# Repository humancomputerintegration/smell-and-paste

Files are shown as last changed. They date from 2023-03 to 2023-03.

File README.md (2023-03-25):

# Smell & Paste toolkit

This is a repository for the Smell & Paste low-fidelity prototyping toolkit for olfactory experiences, which was presented at ACM CHI 2023. The kit is a cassette that takes in scratch-and-sniff stickers by [Jas Brooks](https://jasbrooks.net) and [Pedro Lopes](https://plopes.org) at the University of Chicago's [Human Computer Integration Lab](https://lab.plopes.org/).

[Paper](https://lab.plopes.org/published/2023-CHI-SmellPaste.pdf) | [CHI Talk Video](https://youtu.be/vVBhl13b0PE)

**Original Paper Abstract:** Low-fidelity prototyping is so foundational to Human-Computer Interaction, appearing in most early design phases. So, how do experts prototype olfactory experiences? We interviewed eight experts and found that _they do not_ because _no process supports this_. Thus, we engineered Smell & Paste, a low-fidelity prototyping toolkit. Designers assemble olfactory proofs-of-concept by pasting scratch-and-sniff stickers onto a paper tape. Then, they test the interaction by advancing the tape in our 3D-printed (or cardboard) cassette, which releases the smells via scratching. Our toolkit uses commodity materials; keeps iterations quick, approachable, and cheap; and circumvents electronics, programming, and chemical handling. We evaluated Smell & Paste in two studies. We found that the toolkit was approachable to people of any technical background and that novices and experts appropriated and extended the toolkit, making it personalized. Novices produced prototypes quickly, and experts were excited about the kit's technical affordances and integrating it into their practice.

## Putting together a kit

So you want to try out Smell & Paste!

### 3D Printed version

`3D_Print` contains all the files for the 3D printed version of the cassette. It contains both the parametric Fusion 360 file (`Cassette_3dPrinted_v69.f3d`) as well as all the STL files for printing off the bat (`\STL`). You will have to print two of the rollers (`SaP_Nylon_Roller.stl`) and spools (`SaP_Nylon_Spool.stl`) for one cassette.

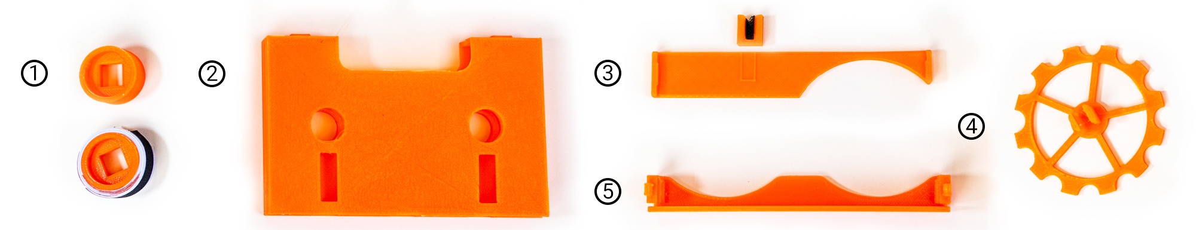
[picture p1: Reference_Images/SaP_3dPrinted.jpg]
Photographs of the 3D printed kit laid out.


| Item | Sourcing | Quantity | Example Source | Unit Cost  | Total Cost | Note |
|---|---|---|---|---|---|---|
| [Case (Bottom)](https://github.com/humancomputerintegration/smell-and-paste/blob/main/3D_Print/STL/SaP_Nylon_CaseBottom.stl) | 3D Print | 1 | | ~ | ~ | |
| [Case (Top)](https://github.com/humancomputerintegration/smell-and-paste/blob/main/3D_Print/STL/SaP_Nylon_CaseTop.stl) | 3D Print | 1 | | ~ | ~ | |
| [Scratch plate](https://github.com/humancomputerintegration/smell-and-paste/blob/main/3D_Print/STL/SaP_Nylon_ScratchPlate.stl) | 3D Print | 1 | | ~ | ~ | |
| [Comb](https://github.com/humancomputerintegration/smell-and-paste/blob/main/3D_Print/STL/SaP_Nylon_Comb.stl) | 3D Print | 1 | | ~ | ~ | |
| [Driver](https://github.com/humancomputerintegration/smell-and-paste/blob/main/3D_Print/STL/SaP_Nylon_Driver.stl) | 3D Print | 1 | | ~ | ~ | |
| [Idle rollers](https://github.com/humancomputerintegration/smell-and-paste/blob/main/3D_Print/STL/SaP_Nylon_Roller.stl) | 3D Print | 2 | | ~ | ~ | |
| [Spools](https://github.com/humancomputerintegration/smell-and-paste/blob/main/3D_Print/STL/SaP_Nylon_Spool.stl) | 3D Print | 2 | | ~ | ~ | |
| Ream of Printer/Copy Paper (20lb) | At home or Purchase | 1 | | $10.00 | $10.00 | Any kind of paper at home works! |
| Tape (Splicing) | At home or Purchase | 1 | [Bari Zaki Studio](https://www.barizaki.com/shop/washi-tape-bookshelf) | $6.00 | $6.00 | Preferably a flexible tape like painter's tape. We recommend Washi tape for how thin and flexible it is! |
| Tape (Spool) | At home or Purchase | 1 | [Home Depot](https://www.homedepot.com/p/Nashua-Tape-1-89-in-x-55-yd-394-General-Purpose-Duct-Tape-in-Silver-Sealer-1529728/100080300) | $4.88 | $4.88 | Preferably a stickier tape to bind the paper tape to the spools. We recommend cheap duct tape. |
| Super glue | At home or Purchase | 1 | [Home Depot](https://www.homedepot.com/p/Loctite-0-14-fl-oz-Ultra-Gel-Control-Super-Glue-1363589/202020461) | $5.68 | $5.68 | To glue the hinges for the 3D printed cassette. Alternatively, you can use duct tape as a hinge. |
| Velcro (hook-and-loop fasteners) with Sticky Backing	| At home or Purchase | 1  | [Home Depot](https://www.homedepot.com/p/VELCRO-Brand-3-1-2-in-x-3-4-in-Sticky-Back-Strips-4-Pack-90075/202261913) | $3.28 | $3.28 | For the comb. |
| Scratch-and-sniff stickers! | At home or Purchase | ~ | Check out Dataset | ~ | ~ | |
| | | | | **Total Cost** | $29.84 | To get things started! |

Please consider sourcing materials from local stores instead of Amazon, if you can! A lot of these items can be found in your home, hardware stores, general stores, and stationary stores.

All 3D printed parts do not need any support structures except for the spools (and - even then - could probably do fine without).

### Cardboard version

`Cardboard` contains all the files for the cardboard version of the cassette. It contains one version for lasercutters (`\Lasercut`) and one for manual cutting using an Xacto knife (`\Manual`). Please note that if you are lasercutting the cardboard version, you will have to leave the pieces to ventilate so that there is no residual burn odor (you can also adjust the settings to decrease burning as much as possible, and can also put the pieces with an ozone generator to speed up the deodorization). For manual cutting, print out the pages (PDF) and paste them on 2.5 mm cardboard. Then use an exacto knife to follow lines.

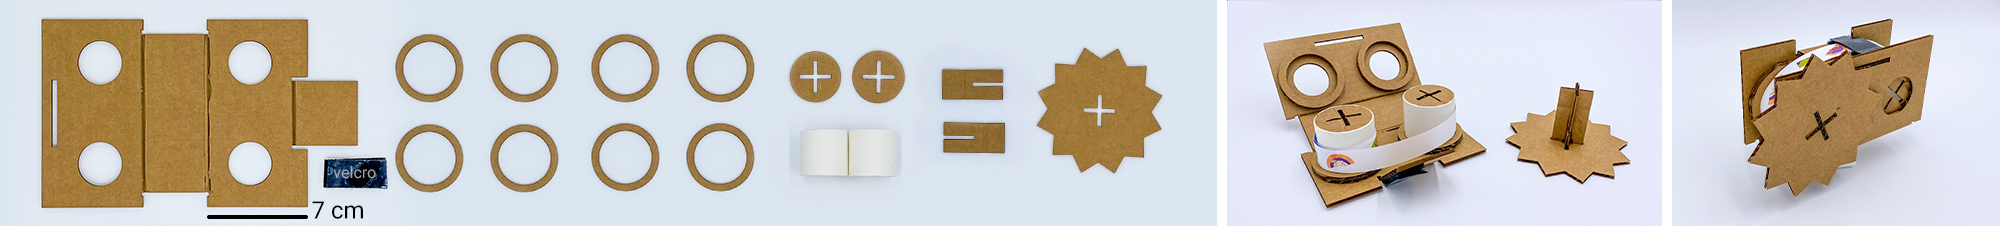
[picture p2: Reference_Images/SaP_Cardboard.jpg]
Photographs of the cardboard kit laid out and assembled.


| Item | Sourcing | Quantity | Example Source | Unit Cost  | Total Cost | Note |
|---|---|---|---|---|---|---|
| Cardboard (2.75mm) | 3D Print | 2 | | ~ | ~ | Amazon packages are typically the perfect thickness for this. |
| 1.6in Diameter Paper Tube (Spools) | 3D Print | 2 | | ~ | ~ | Cut the tube to have 2 tubes of length 4cm. |
| Ream of Printer/Copy Paper (20lb) | At home or Purchase | 1 | | $10.00 | $10.00 | Any kind of paper at home works! |
| Tape (Splicing) | At home or Purchase | 1 | [Bari Zaki Studio](https://www.barizaki.com/shop/washi-tape-bookshelf) | $6.00 | $6.00 | Preferably a flexible tape like painter's tape. We recommend Washi tape for how thin and flexible it is! |
| Tape (Spool) | At home or Purchase | 1 | [Home Depot](https://www.homedepot.com/p/Nashua-Tape-1-89-in-x-55-yd-394-General-Purpose-Duct-Tape-in-Silver-Sealer-1529728/100080300) | $4.88 | $4.88 | Preferably a stickier tape to bind the paper tape to the spools. We recommend cheap duct tape. |
| Glue stick | At home or Purchase | 1 | [Walgreens](https://www.walgreens.com/store/c/elmer's-disappearing-purple-school-glue-sticks/ID=prod17798-product) | $3.79 | $3.79 | To glue cardboard pieces together. together. |
| Velcro (hook-and-loop fasteners) with Sticky Backing | At home or Purchase | 1 | [Home Depot](https://www.homedepot.com/p/VELCRO-Brand-3-1-2-in-x-3-4-in-Sticky-Back-Strips-4-Pack-90075/202261913) | $3.28 | $3.28 | For comb. |
| Scratch-and-sniff stickers! | At home or Purchase | ~ | | ~ | ~ | |
| | | | | Total Cost | $26.56 | To get things started! |

Please consider sourcing materials from local stores instead of Amazon, if you can! A lot of these items can be found in your home, hardware stores, general stores, and stationary stores.

### Sourcing scratch-and-sniff stickers

For our toolkit to be practical, you'll need scratch-and-sniff stickers. Commercial scratch-and-sniff stickers for children are incredibly accessible and cheap, including good and bad scents. We created a dataset of 800 scratch-and-sniff stickers from 22 brands to facilitate sticker selection. We manually extracted each sticker’s scent, dimensions, and price per cm2. The dataset includes (nominally) 538 unique scents, depicting a wide variety at costs as low as 0.00035 USD per cm2. [You can find its CSV here!](https://github.com/humancomputerintegration/smell-and-paste/blob/main/CommercialSaS_v00.csv) (Jas recommends Just For Laughs' [Stink Factory stickers](https://www.thestinkfactory.com/) for their odor variety and reasonable prices.)

## Licensing & Citing

The cassette and documentation is released under the CC BY 4.0 License (just needs attribution to Jas Brooks and Pedro Lopes). We encourage people to remix this to their heart's content!

When using or building upon this device or dataset **in an academic publication**, please consider citing our paper:

Jas Brooks and Pedro Lopes. 2023. “Smell & Paste: Low-Fidelity Prototyping for Olfactory Experiences.” In Proceedings of the 2023 CHI Conference on Human Factors in Computing Systems (CHI ’23). Association for Computing Machinery, New York, NY, USA. DOI:10.1145/3544548.3580680

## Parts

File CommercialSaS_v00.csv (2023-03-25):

Vendor Country | Distributor | Brand | Scent | URL | Production Status | Cost ($) | Unit | Count | Price per Unit ($) | Usable Area Dimensions (cm) | Usable Unit Surface Area (cm2) | Price per cm2 ($/cm2) | Assortment | Purchased | Accessed | Notes
US | Horiey | Horiechaly | Bubblegum | https://www.amazon.com/HORIECHALY-Stickers-Different-Teachers-Stickers/dp/B088D5HZJ5/ |  | $ 14.97 | Sheet | 80 | $ 0.19 | 31.75 x 17.022 | 540.32 | 0.00035 | Mixed |  | 2020/11/06
US | Horiey | Horiechaly | Rose | https://www.amazon.com/HORIECHALY-Stickers-Different-Teachers-Stickers/dp/B088D5HZJ5/ |  | $ 14.97 | Sheet | 80 | $ 0.19 | 31.75 x 17.038 | 540.32 | 0.00035 | Mixed |  | 2020/11/06
US | Horiey | Horiechaly | Apple | https://www.amazon.com/HORIECHALY-Stickers-Different-Teachers-Stickers/dp/B07Z4C5DNJ |  | $ 15.97 | Sheet | 68 | $ 0.23 | 31.75 x 17.018 | 540.32 | 0.00043 | Mixed |  | 2020/11/06
US | Horiey | Horiechaly | Avocado | https://www.amazon.com/HORIECHALY-Stickers-Different-Teachers-Stickers/dp/B07Z4C5DNJ |  | $ 15.97 | Sheet | 68 | $ 0.23 | 31.75 x 17.019 | 540.32 | 0.00043 | Mixed |  | 2020/11/06
US | Horiey | Horiechaly | Banana | https://www.amazon.com/HORIECHALY-Stickers-Different-Teachers-Stickers/dp/B07Z4C5DNJ |  | $ 15.97 | Sheet | 68 | $ 0.23 | 31.75 x 17.020 | 540.32 | 0.00043 | Mixed |  | 2020/11/06
US | Horiey | Horiechaly | Blueberry | https://www.amazon.com/HORIECHALY-Stickers-Different-Teachers-Stickers/dp/B07Z4C5DNJ |  | $ 15.97 | Sheet | 68 | $ 0.23 | 31.75 x 17.021 | 540.32 | 0.00043 | Mixed |  | 2020/11/06
US | Horiey | Horiechaly | Cola | https://www.amazon.com/HORIECHALY-Stickers-Different-Teachers-Stickers/dp/B07Z4C5DNJ |  | $ 15.97 | Sheet | 68 | $ 0.23 | 31.75 x 17.026 | 540.32 | 0.00043 | Mixed |  | 2020/11/06
US | Horiey | Horiechaly | Gardenia | https://www.amazon.com/HORIECHALY-Stickers-Different-Teachers-Stickers/dp/B07Z4C5DNJ |  | $ 15.97 | Sheet | 68 | $ 0.23 | 31.75 x 17.028 | 540.32 | 0.00043 | Mixed |  | 2020/11/06
US | Horiey | Horiechaly | Grape | https://www.amazon.com/HORIECHALY-Stickers-Different-Teachers-Stickers/dp/B07Z4C5DNJ |  | $ 15.97 | Sheet | 68 | $ 0.23 | 31.75 x 17.029 | 540.32 | 0.00043 | Mixed |  | 2020/11/06
US | Horiey | Horiechaly | Lavender | https://www.amazon.com/HORIECHALY-Stickers-Different-Teachers-Stickers/dp/B07Z4C5DNJ |  | $ 15.97 | Sheet | 68 | $ 0.23 | 31.75 x 17.030 | 540.32 | 0.00043 | Mixed |  | 2020/11/06
US | Horiey | Horiechaly | Lemon | https://www.amazon.com/HORIECHALY-Stickers-Different-Teachers-Stickers/dp/B07Z4C5DNJ |  | $ 15.97 | Sheet | 68 | $ 0.23 | 31.75 x 17.031 | 540.32 | 0.00043 | Mixed |  | 2020/11/06
US | Horiey | Horiechaly | Mango | https://www.amazon.com/HORIECHALY-Stickers-Different-Teachers-Stickers/dp/B07Z4C5DNJ |  | $ 15.97 | Sheet | 68 | $ 0.23 | 31.75 x 17.032 | 540.32 | 0.00043 | Mixed |  | 2020/11/06
US | Horiey | Horiechaly | Orange | https://www.amazon.com/HORIECHALY-Stickers-Different-Teachers-Stickers/dp/B07Z4C5DNJ |  | $ 15.97 | Sheet | 68 | $ 0.23 | 31.75 x 17.033 | 540.32 | 0.00043 | Mixed |  | 2020/11/06
US | Horiey | Horiechaly | Peach | https://www.amazon.com/HORIECHALY-Stickers-Different-Teachers-Stickers/dp/B07Z4C5DNJ |  | $ 15.97 | Sheet | 68 | $ 0.23 | 31.75 x 17.034 | 540.32 | 0.00043 | Mixed |  | 2020/11/06
US | Horiey | Horiechaly | Pineapple | https://www.amazon.com/HORIECHALY-Stickers-Different-Teachers-Stickers/dp/B07Z4C5DNJ |  | $ 15.97 | Sheet | 68 | $ 0.23 | 31.75 x 17.036 | 540.32 | 0.00043 | Mixed |  | 2020/11/06
US | Horiey | Horiechaly | Raspberry | https://www.amazon.com/HORIECHALY-Stickers-Different-Teachers-Stickers/dp/B07Z4C5DNJ |  | $ 15.97 | Sheet | 68 | $ 0.23 | 31.75 x 17.037 | 540.32 | 0.00043 | Mixed |  | 2020/11/06
US | Horiey | Horiechaly | Strawberry | https://www.amazon.com/HORIECHALY-Stickers-Different-Teachers-Stickers/dp/B07Z4C5DNJ |  | $ 15.97 | Sheet | 68 | $ 0.23 | 31.75 x 17.039 | 540.32 | 0.00043 | Mixed |  | 2020/11/06
US | Horiey | Horiechaly | Vanilla | https://www.amazon.com/HORIECHALY-Stickers-Different-Teachers-Stickers/dp/B07Z4C5DNJ |  | $ 15.97 | Sheet | 68 | $ 0.23 | 31.75 x 17.040 | 540.32 | 0.00043 | Mixed |  | 2020/11/06
US | Horiey | Horiechaly | Watermelon | https://www.amazon.com/HORIECHALY-Stickers-Different-Teachers-Stickers/dp/B07Z4C5DNJ |  | $ 15.97 | Sheet | 68 | $ 0.23 | 31.75 x 17.041 | 540.32 | 0.00043 | Mixed |  | 2020/11/06
US | Horiey | Horiechaly | Cake | https://www.amazon.com/HORIECHALY-Scratch-Stickers-Teachers-Birthday/dp/B07YCDVNKP/ |  | $ 12.97 | Sheet | 48 | $ 0.27 | 31.75 x 17.023 | 540.32 | 0.00050 | Mixed |  | 2020/11/06
US | Horiey | Horiechaly | Cherry | https://www.amazon.com/HORIECHALY-Scratch-Stickers-Teachers-Birthday/dp/B07YCDVNKP/ |  | $ 12.97 | Sheet | 48 | $ 0.27 | 31.75 x 17.024 | 540.32 | 0.00050 | Mixed |  | 2020/11/06
US | Horiey | Horiechaly | Chocolate | https://www.amazon.com/HORIECHALY-Scratch-Stickers-Teachers-Birthday/dp/B07YCDVNKP/ |  | $ 12.97 | Sheet | 48 | $ 0.27 | 31.75 x 17.025 | 540.32 | 0.00050 | Mixed |  | 2020/11/06
US | Horiey | Horiechaly | Corn | https://www.amazon.com/HORIECHALY-Scratch-Stickers-Teachers-Birthday/dp/B07YCDVNKP/ |  | $ 12.97 | Sheet | 48 | $ 0.27 | 31.75 x 17.027 | 540.32 | 0.00050 | Mixed |  | 2020/11/06
US | Horiey | Horiechaly | Peppermint | https://www.amazon.com/HORIECHALY-Scratch-Stickers-Teachers-Birthday/dp/B07YCDVNKP/ |  | $ 12.97 | Sheet | 48 | $ 0.27 | 31.75 x 17.035 | 540.32 | 0.00050 | Mixed |  | 2020/11/06
US | Apurimac Co., Limited | Purple Ladybug | Apple | https://www.amazon.com/Purple-Ladybug-Novelty-Stickers-Different/dp/B01MY9ST0J/ |  | $ 10.99 | Sheet | 45 | $ 0.24 | 19.304 x 11.43 | 220.64 | 0.00111 | Mixed |  | 2020/11/06
US | Apurimac Co., Limited | Purple Ladybug | Banana | https://www.amazon.com/Purple-Ladybug-Novelty-Stickers-Different/dp/B01MY9ST0J/ |  | $ 10.99 | Sheet | 45 | $ 0.24 | 19.304 x 11.44 | 220.64 | 0.00111 | Mixed |  | 2020/11/06
US | Apurimac Co., Limited | Purple Ladybug | Blueberry | https://www.amazon.com/Purple-Ladybug-Novelty-Stickers-Different/dp/B01MY9ST0J/ |  | $ 10.99 | Sheet | 45 | $ 0.24 | 19.304 x 11.45 | 220.64 | 0.00111 | Mixed |  | 2020/11/06
US | Apurimac Co., Limited | Purple Ladybug | Cake | https://www.amazon.com/Purple-Ladybug-Novelty-Stickers-Different/dp/B01MY9ST0J/ |  | $ 10.99 | Sheet | 45 | $ 0.24 | 19.304 x 11.46 | 220.64 | 0.00111 | Mixed |  | 2020/11/06
US | Apurimac Co., Limited | Purple Ladybug | Cherry | https://www.amazon.com/Purple-Ladybug-Novelty-Stickers-Different/dp/B01MY9ST0J/ |  | $ 10.99 | Sheet | 45 | $ 0.24 | 19.304 x 11.47 | 220.64 | 0.00111 | Mixed |  | 2020/11/06
US | Apurimac Co., Limited | Purple Ladybug | Chocolate | https://www.amazon.com/Purple-Ladybug-Novelty-Stickers-Different/dp/B01MY9ST0J/ |  | $ 10.99 | Sheet | 45 | $ 0.24 | 19.304 x 11.48 | 220.64 | 0.00111 | Mixed |  | 2020/11/06
US | Apurimac Co., Limited | Purple Ladybug | Corn | https://www.amazon.com/Purple-Ladybug-Novelty-Stickers-Different/dp/B01MY9ST0J/ |  | $ 10.99 | Sheet | 45 | $ 0.24 | 19.304 x 11.49 | 220.64 | 0.00111 | Mixed |  | 2020/11/06
US | Apurimac Co., Limited | Purple Ladybug | Grape | https://www.amazon.com/Purple-Ladybug-Novelty-Stickers-Different/dp/B01MY9ST0J/ |  | $ 10.99 | Sheet | 45 | $ 0.24 | 19.304 x 11.50 | 220.64 | 0.00111 | Mixed |  | 2020/11/06
US | Apurimac Co., Limited | Purple Ladybug | Lemon | https://www.amazon.com/Purple-Ladybug-Novelty-Stickers-Different/dp/B01MY9ST0J/ |  | $ 10.99 | Sheet | 45 | $ 0.24 | 19.304 x 11.51 | 220.64 | 0.00111 | Mixed |  | 2020/11/06
US | Apurimac Co., Limited | Purple Ladybug | Orange | https://www.amazon.com/Purple-Ladybug-Novelty-Stickers-Different/dp/B01MY9ST0J/ |  | $ 10.99 | Sheet | 45 | $ 0.24 | 19.304 x 11.52 | 220.64 | 0.00111 | Mixed |  | 2020/11/06
US | Apurimac Co., Limited | Purple Ladybug | Peach | https://www.amazon.com/Purple-Ladybug-Novelty-Stickers-Different/dp/B01MY9ST0J/ |  | $ 10.99 | Sheet | 45 | $ 0.24 | 19.304 x 11.53 | 220.64 | 0.00111 | Mixed |  | 2020/11/06
US | Apurimac Co., Limited | Purple Ladybug | Peppermint | https://www.amazon.com/Purple-Ladybug-Novelty-Stickers-Different/dp/B01MY9ST0J/ |  | $ 10.99 | Sheet | 45 | $ 0.24 | 19.304 x 11.54 | 220.64 | 0.00111 | Mixed |  | 2020/11/06
US | Apurimac Co., Limited | Purple Ladybug | Raspberry | https://www.amazon.com/Purple-Ladybug-Novelty-Stickers-Different/dp/B01MY9ST0J/ |  | $ 10.99 | Sheet | 45 | $ 0.24 | 19.304 x 11.55 | 220.64 | 0.00111 | Mixed |  | 2020/11/06
US | Apurimac Co., Limited | Purple Ladybug | Strawberry | https://www.amazon.com/Purple-Ladybug-Novelty-Stickers-Different/dp/B01MY9ST0J/ |  | $ 10.99 | Sheet | 45 | $ 0.24 | 19.304 x 11.56 | 220.64 | 0.00111 | Mixed |  | 2020/11/06
US | Apurimac Co., Limited | Purple Ladybug | Watermelon | https://www.amazon.com/Purple-Ladybug-Novelty-Stickers-Different/dp/B01MY9ST0J/ |  | $ 10.99 | Sheet | 45 | $ 0.24 | 19.304 x 11.57 | 220.64 | 0.00111 | Mixed |  | 2020/11/06
US | Paper Magic Group, Inc. | Eureka | Candy Cane | https://www.everythingsmells.com/collections/all-of-our-scented-stickers/products/christmas-scratch-and-smell-scented-stickers-variety-pack-by-eureka-limited-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 | OOS | $ 12.99 | Sheet | 24 | $ 0.54 | 14.605 x 22.86 | 333.9 | 0.00162 | Mixed |  | 2020/11/06
US | Paper Magic Group, Inc. | Eureka | Hot Cocoa | https://www.everythingsmells.com/collections/all-of-our-scented-stickers/products/christmas-scratch-and-smell-scented-stickers-variety-pack-by-eureka-limited-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 | OOS | $ 12.99 | Sheet | 24 | $ 0.54 | 14.605 x 22.86 | 333.9 | 0.00162 | Mixed |  | 2020/11/06
US | Paper Magic Group, Inc. | Eureka | Pine | https://www.everythingsmells.com/collections/all-of-our-scented-stickers/products/christmas-scratch-and-smell-scented-stickers-variety-pack-by-eureka-limited-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 | OOS | $ 12.99 | Sheet | 24 | $ 0.54 | 14.605 x 22.86 | 333.9 | 0.00162 | Mixed |  | 2020/11/06
US | Paper Magic Group, Inc. | Eureka | Sugar Cookies | https://www.everythingsmells.com/collections/all-of-our-scented-stickers/products/christmas-scratch-and-smell-scented-stickers-variety-pack-by-eureka-limited-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 | OOS | $ 12.99 | Sheet | 24 | $ 0.54 | 14.605 x 22.86 | 333.9 | 0.00162 | Single |  | 2020/11/06
US | Paper Magic Group, Inc. | Eureka | Bacon | https://www.everythingsmells.com/collections/all-of-our-scented-stickers/products/bacon-scented-stickers-by-eureka |  | $ 2.99 | Sheet | 4 | $ 0.75 | 14.605 x 22.86 | 333.9 | 0.00224 | Single | Yes | 2020/11/06
US | Paper Magic Group, Inc. | Eureka | Banana | https://www.everythingsmells.com/products/banana-scented-stickers-80-stickers-new |  | $ 2.99 | Sheet | 4 | $ 0.75 | 14.605 x 22.86 | 333.9 | 0.00224 | Single |  | 2020/11/06
US | Paper Magic Group, Inc. | Eureka | Bubblegum | https://www.everythingsmells.com/collections/all-of-our-scented-stickers/products/bubble-gum-scented-stickers-80-stickers-new |  | $ 2.99 | Sheet | 4 | $ 0.75 | 14.605 x 22.86 | 333.9 | 0.00224 | Single |  | 2020/11/06
US | Paper Magic Group, Inc. | Eureka | Cherry | https://www.everythingsmells.com/collections/all-of-our-scented-stickers/products/cherry-scented-stickers-by-eureka |  | $ 2.99 | Sheet | 4 | $ 0.75 | 14.605 x 22.86 | 333.9 | 0.00224 | Single |  | 2020/11/06
US | Paper Magic Group, Inc. | Eureka | Chocolate | https://www.everythingsmells.com/collections/all-of-our-scented-stickers/products/chocolate-scented-stickers-by-eureka-new |  | $ 2.99 | Sheet | 4 | $ 0.75 | 14.605 x 22.86 | 333.9 | 0.00224 | Single |  | 2020/11/06
US | Paper Magic Group, Inc. | Eureka | Cinnamon Toast | https://www.everythingsmells.com/collections/all-of-our-scented-stickers/products/cinnamon-toast-scented-stickers-80-stickers | OOS | $ 2.99 | Sheet | 4 | $ 0.75 | 14.605 x 22.86 | 333.9 | 0.00224 | Single |  | 2020/11/06
US | Paper Magic Group, Inc. | Eureka | Coconut | https://www.everythingsmells.com/collections/all-of-our-scented-stickers/products/coconut-scented-stickers-80-stickers |  | $ 2.99 | Sheet | 4 | $ 0.75 | 14.605 x 22.86 | 333.9 | 0.00224 | Single |  | 2020/11/06
US | Paper Magic Group, Inc. | Eureka | Cola | https://www.everythingsmells.com/collections/all-of-our-scented-stickers/products/cola-scented-stickers-by-eureka-new |  | $ 2.99 | Sheet | 4 | $ 0.75 | 14.605 x 22.86 | 333.9 | 0.00224 | Single |  | 2020/11/06
US | Paper Magic Group, Inc. | Eureka | Grape | https://www.everythingsmells.com/collections/all-of-our-scented-stickers/products/grape-scented-stickers-by-eureka-new |  | $ 2.99 | Sheet | 4 | $ 0.75 | 14.605 x 22.86 | 333.9 | 0.00224 | Single |  | 2020/11/06
US | Paper Magic Group, Inc. | Eureka | Honey | https://www.everythingsmells.com/collections/all-of-our-scented-stickers/products/honey-bees-scented-stickers-80-stickers | OOS | $ 2.99 | Sheet | 4 | $ 0.75 | 14.605 x 22.86 | 333.9 | 0.00224 | Single |  | 2020/11/06
US | Paper Magic Group, Inc. | Eureka | Jellybean | https://www.everythingsmells.com/collections/all-of-our-scented-stickers/products/jelly-bean-scented-stickers-80-stickers |  | $ 2.99 | Sheet | 4 | $ 0.75 | 14.605 x 22.86 | 333.9 | 0.00224 | Single |  | 2020/11/06
US | Paper Magic Group, Inc. | Eureka | Lemon | https://www.everythingsmells.com/collections/all-of-our-scented-stickers/products/lemon-scented-stickers-80-stickers-new |  | $ 2.99 | Sheet | 4 | $ 0.75 | 14.605 x 22.86 | 333.9 | 0.00224 | Single |  | 2020/11/06
US | Paper Magic Group, Inc. | Eureka | Marshmallow | https://www.everythingsmells.com/collections/all-of-our-scented-stickers/products/marshmallow-smores-scented-stickers-80-stickers | OOS | $ 2.99 | Sheet | 4 | $ 0.75 | 14.605 x 22.86 | 333.9 | 0.00224 | Single |  | 2020/11/06
US | Paper Magic Group, Inc. | Eureka | Mint | https://www.everythingsmells.com/collections/all-of-our-scented-stickers/products/mint-scented-stickers-by-eureka-new |  | $ 2.99 | Sheet | 4 | $ 0.75 | 14.605 x 22.86 | 333.9 | 0.00224 | Single |  | 2020/11/06
US | Paper Magic Group, Inc. | Eureka | Orange | https://www.everythingsmells.com/collections/all-of-our-scented-stickers/products/orange-scented-stickers-80-stickers |  | $ 2.99 | Sheet | 4 | $ 0.75 | 14.605 x 22.86 | 333.9 | 0.00224 | Single |  | 2020/11/06
US | Paper Magic Group, Inc. | Eureka | Peach | https://www.everythingsmells.com/collections/all-of-our-scented-stickers/products/peach-scented-stickers-by-eureka-new |  | $ 2.99 | Sheet | 4 | $ 0.75 | 14.605 x 22.86 | 333.9 | 0.00224 | Single |  | 2020/11/06
US | Paper Magic Group, Inc. | Eureka | Popcorn | https://www.everythingsmells.com/collections/all-of-our-scented-stickers/products/popcorn-carnival-scented-stickers-80-stickers |  | $ 2.99 | Sheet | 4 | $ 0.75 | 14.605 x 22.86 | 333.9 | 0.00224 | Single |  | 2020/11/06
US | Paper Magic Group, Inc. | Eureka | Strawberry | https://www.everythingsmells.com/collections/all-of-our-scented-stickers/products/strawberry-scented-stickers-80-stickers |  | $ 2.99 | Sheet | 4 | $ 0.75 | 14.605 x 22.86 | 333.9 | 0.00224 | Single |  | 2020/11/06
US | MediBadge, Inc. | MediBadge, Inc. | Scooby-Doo Fruity Snacks | https://www.medibadge.com/Scooby-Doo-Fruity-Snacks-Scratch-n-Sniff-Stickers-P5115.aspx |  | $ 6.99 | Sticker | 75 | $ 0.09 | 6.35 | 40.32 | 0.00231 | Single |  | 2020/11/06
US | MediBadge, Inc. | MediBadge, Inc. | Strawberry | https://www.medibadge.com/Dora-Sweet-Strawberry-Scratch-n-Sniff-Stickers-P6091.aspx |  | $ 6.99 | Sticker | 75 | $ 0.09 | 6.35 | 40.32 | 0.00231 | Single |  | 2020/11/06
US |  | SmileMakers, Inc. | Gingerbread House | https://www.smilemakers.com/scented-gingerbread-houses-stickers.html |  | $ 6.99 | Sticker | 75 | $ 0.09 | 6.35 | 40.32 | 0.00231 | Single |  | 2020/11/06
US |  | SmileMakers, Inc. | Peppermint | https://www.smilemakers.com/scented-peppermint-penguins-stickers.html |  | $ 6.99 | Sticker | 75 | $ 0.09 | 6.35 | 40.32 | 0.00231 | Single |  | 2020/11/06
US |  | SmileMakers, Inc. | Pickle | https://www.smilemakers.com/pickle%20scented%20dinosaur%20stickers.html |  | $ 6.99 | Sticker | 75 | $ 0.09 | 6.35 | 40.32 | 0.00231 | Single |  | 2020/11/06
US |  | SmileMakers, Inc. | Tropical | https://www.smilemakers.com/tropical%20scented%20birds%20stickers.html |  | $ 6.99 | Sticker | 75 | $ 0.09 | 6.35 | 40.32 | 0.00231 | Single | Yes | 2020/11/06 | Potentially pineapple
US | Paper Magic Group, Inc. | Eureka | Candy Corn | https://www.everythingsmells.com/collections/all-of-our-scented-stickers/products/candy-corn-costumes-scratch-and-smell-sticker-sheets-2 |  | $ 1.95 | Sheet | 2 | $ 0.98 | 14.605 x 22.86 | 333.9 | 0.00292 | Single |  | 2020/11/06
US | Paper Magic Group, Inc. | Eureka | Garlic | https://www.everythingsmells.com/collections/all-of-our-scented-stickers/products/stinky-vampire-scratch-and-smell-garlic-scented-stickers-by-eureka-limited-e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 |  | $ 1.95 | Sheet | 2 | $ 0.98 | 14.605 x 22.86 | 333.9 | 0.00292 | Single | Yes | 2020/11/06
US | MediBadge, Inc. | MediBadge, Inc. | Cupcake | https://www.medibadge.com/Cupcake-Cuties-Scratch-n-Sniff-Asst-Scented-Stickers-P5255.aspx |  | $ 6.99 | Sticker | 75 | $ 0.09 | 6.35 | 31.67 | 0.00294 | Single |  | 2020/11/06
US | MediBadge, Inc. | MediBadge, Inc. | Fruit Punch | https://www.medibadge.com/Fruit-Punch-Smiles-Scratch-n-Sniff-Asst-Scented-Stickers-P3533.aspx |  | $ 6.99 | Sticker | 75 | $ 0.09 | 6.35 | 31.67 | 0.00294 | Single |  | 2020/11/06
US |  | SmileMakers, Inc. | Fruity | https://www.smilemakers.com/fruity-scratch-n-sniff-stickers.html |  | $ 6.99 | Sticker | 75 | $ 0.09 | 6.35 | 31.67 | 0.00294 | Single |  | 2020/11/06
US | Super Duper Publications | Speech Sniffys | Cinnamon | https://www.everythingsmells.com/collections/all-of-our-scented-stickers/products/speech-sniffys-super-pack-scented-speech-stickers-90-sheets-new | OOS | $ 29.95 | Sticker | 1080 | $ 0.03 | 3.4 | 9.08 | 0.00305 | Mixed | Yes | 2020/11/06
US |  | SmileMakers, Inc. | Gumdrop | https://www.smilemakers.com/candy-land-scented-stickers.html |  | $ 6.99 | Sticker | 50 | $ 0.14 | 6.35 | 40.32 | 0.00347 | Single |  | 2020/11/06
US | Standard Publishing | Faith That Sticks | Floral | https://www.everythingsmells.com/collections/all-of-our-scented-stickers/products/happy-flowers-stick-n-sniff-stickers | OOS | $ 2.50 | Sheet | 6 | $ 0.42 | 10 x 10 | 100.00 | 0.00417 | Single |  | 2020/11/06
US |  | Crayola | Bubblegum | https://www.everythingsmells.com/collections/all-of-our-scented-stickers/products/jumbo-bubble-gum-ball-crayola-silly-scents-scratch-sniff-stickers-new |  | $ 1.50 | Sticker | 2 | $ 0.75 | 13.97 | 153.28 | 0.00489 | Single |  | 2020/11/06
US | JFL Enterprises, Inc. | Stink Factory | Apple | https://www.thestinkfactory.com/stickers/apple_sticker.html |  | $ 2.00 | Sheet | 2 | $ 1.00 | 10.16 x 17.145 | 174.19 | 0.00574 | Single |  | 2020/11/06
US | JFL Enterprises, Inc. | Stink Factory | Apple Pie | https://www.thestinkfactory.com/stickers/apple-pie_sticker.html |  | $ 2.00 | Sheet | 2 | $ 1.00 | 10.16 x 17.146 | 174.19 | 0.00574 | Single |  | 2020/11/06
US | JFL Enterprises, Inc. | Stink Factory | Baby Powder | https://www.thestinkfactory.com/stickers/Baby-Powder_sticker.html |  | $ 2.00 | Sheet | 2 | $ 1.00 | 10.16 x 17.147 | 174.19 | 0.00574 | Single |  | 2020/11/06
US | JFL Enterprises, Inc. | Stink Factory | Bacon | https://www.thestinkfactory.com/stickers/bacon_sticker.html |  | $ 2.00 | Sheet | 2 | $ 1.00 | 10.16 x 17.148 | 174.19 | 0.00574 | Single |  | 2020/11/06
US | JFL Enterprises, Inc. | Stink Factory | Banana | https://www.thestinkfactory.com/stickers/banana_sticker.html |  | $ 2.00 | Sheet | 2 | $ 1.00 | 10.16 x 17.149 | 174.19 | 0.00574 | Single |  | 2020/11/06
US | JFL Enterprises, Inc. | Stink Factory | Birthday Cake | https://www.thestinkfactory.com/stickers/birthday_sticker.html |  | $ 2.00 | Sheet | 2 | $ 1.00 | 10.16 x 17.150 | 174.19 | 0.00574 | Single |  | 2020/11/06
US | JFL Enterprises, Inc. | Stink Factory | Blow Pop Blue Raspberry | https://www.thestinkfactory.com/stickers/blow-pop-blue-raspberry.html |  | $ 2.00 | Sheet | 2 | $ 1.00 | 10.16 x 17.151 | 174.19 | 0.00574 | Single |  | 2020/11/06
US | JFL Enterprises, Inc. | Stink Factory | Blow Pop Cherry | https://www.thestinkfactory.com/stickers/blow-pop-cherry.html |  | $ 2.00 | Sheet | 2 | $ 1.00 | 10.16 x 17.152 | 174.19 | 0.00574 | Single |  | 2020/11/06
US | JFL Enterprises, Inc. | Stink Factory | Blow Pop Sour Apple | https://www.thestinkfactory.com/stickers/blow-pop-sour-apple.html |  | $ 2.00 | Sheet | 2 | $ 1.00 | 10.16 x 17.153 | 174.19 | 0.00574 | Single |  | 2020/11/06
US | JFL Enterprises, Inc. | Stink Factory | Blu Snowcone | https://www.thestinkfactory.com/stickers/blu-snowcone_sticker.html |  | $ 2.00 | Sheet | 2 | $ 1.00 | 10.16 x 17.154 | 174.19 | 0.00574 | Single |  | 2020/11/06
US | JFL Enterprises, Inc. | Stink Factory | Blueberry | https://www.thestinkfactory.com/stickers/blueberry_sticker.html |  | $ 2.00 | Sheet | 2 | $ 1.00 | 10.16 x 17.155 | 174.19 | 0.00574 | Single |  | 2020/11/06
US | JFL Enterprises, Inc. | Stink Factory | Bologna | https://www.thestinkfactory.com/stickers/bologna_sticker.html |  | $ 2.00 | Sheet | 2 | $ 1.00 | 10.16 x 17.156 | 174.19 | 0.00574 | Single |  | 2020/11/06
US | JFL Enterprises, Inc. | Stink Factory | Bread | https://www.thestinkfactory.com/stickers/Bread_sticker.html |  | $ 2.00 | Sheet | 2 | $ 1.00 | 10.16 x 17.157 | 174.19 | 0.00574 | Single |  | 2020/11/06
US | JFL Enterprises, Inc. | Stink Factory | Brownie | https://www.thestinkfactory.com/stickers/brownie_sticker.html |  | $ 2.00 | Sheet | 2 | $ 1.00 | 10.16 x 17.158 | 174.19 | 0.00574 | Single |  | 2020/11/06
US | JFL Enterprises, Inc. | Stink Factory | Bubblegum | https://www.thestinkfactory.com/stickers/bubblegum_sticker.html |  | $ 2.00 | Sheet | 2 | $ 1.00 | 10.16 x 17.159 | 174.19 | 0.00574 | Single |  | 2020/11/06
US | JFL Enterprises, Inc. | Stink Factory | Campfire | https://www.thestinkfactory.com/stickers/campfire_sticker.html |  | $ 2.00 | Sheet | 2 | $ 1.00 | 10.16 x 17.160 | 174.19 | 0.00574 | Single |  | 2020/11/06
US | JFL Enterprises, Inc. | Stink Factory | Candy Cane | https://www.thestinkfactory.com/stickers/xmas-DrStinky-candycane.html |  | $ 2.00 | Sheet | 2 | $ 1.00 | 10.16 x 17.161 | 174.19 | 0.00574 | Single |  | 2020/11/06
US | JFL Enterprises, Inc. | Stink Factory | Charleston Chew Vanilla | https://www.thestinkfactory.com/stickers/charleston-chew.html |  | $ 2.00 | Sheet | 2 | $ 1.00 | 10.16 x 17.162 | 174.19 | 0.00574 | Single |  | 2020/11/06
US | JFL Enterprises, Inc. | Stink Factory | Cherry | https://www.thestinkfactory.com/stickers/cherry_sticker.html |  | $ 2.00 | Sheet | 2 | $ 1.00 | 10.16 x 17.163 | 174.19 | 0.00574 | Single |  | 2020/11/06
US | JFL Enterprises, Inc. | Stink Factory | Chili | https://www.thestinkfactory.com/stickers/chili_sticker.html |  | $ 2.00 | Sheet | 2 | $ 1.00 | 10.16 x 17.164 | 174.19 | 0.00574 | Single |  | 2020/11/06
US | JFL Enterprises, Inc. | Stink Factory | Chocolate | https://www.thestinkfactory.com/stickers/chocolate_sticker.html |  | $ 2.00 | Sheet | 2 | $ 1.00 | 10.16 x 17.165 | 174.19 | 0.00574 | Single |  | 2020/11/06
US | JFL Enterprises, Inc. | Stink Factory | Christmas Tree | https://www.thestinkfactory.com/stickers/xmas-DrStinky-tree.html |  | $ 2.00 | Sheet | 2 | $ 1.00 | 10.16 x 17.166 | 174.19 | 0.00574 | Single |  | 2020/11/06
US | JFL Enterprises, Inc. | Stink Factory | Cinnamon Roll | https://www.thestinkfactory.com/stickers/cinnamon_sticker.html |  | $ 2.00 | Sheet | 2 | $ 1.00 | 10.16 x 17.167 | 174.19 | 0.00574 | Single |  | 2020/11/06
US | JFL Enterprises, Inc. | Stink Factory | Coconut | https://www.thestinkfactory.com/stickers/coconut_sticker.html |  | $ 2.00 | Sheet | 2 | $ 1.00 | 10.16 x 17.168 | 174.19 | 0.00574 | Single |  | 2020/11/06
US | JFL Enterprises, Inc. | Stink Factory | Cola | https://www.thestinkfactory.com/stickers/Cola_sticker.html |  | $ 2.00 | Sheet | 2 | $ 1.00 | 10.16 x 17.169 | 174.19 | 0.00574 | Single |  | 2020/11/06
US | JFL Enterprises, Inc. | Stink Factory | Cotton Candy | https://www.thestinkfactory.com/stickers/cottoncandy_sticker.html |  | $ 2.00 | Sheet | 2 | $ 1.00 | 10.16 x 17.170 | 174.19 | 0.00574 | Single |  | 2020/11/06
US | JFL Enterprises, Inc. | Stink Factory | Cough Drop | https://www.thestinkfactory.com/stickers/Cough-Drop_sticker.html |  | $ 2.00 | Sheet | 2 | $ 1.00 | 10.16 x 17.171 | 174.19 | 0.00574 | Single |  | 2020/11/06
US | JFL Enterprises, Inc. | Stink Factory | Cow | https://www.thestinkfactory.com/stickers/cow_sticker.html |  | $ 2.00 | Sheet | 2 | $ 1.00 | 10.16 x 17.172 | 174.19 | 0.00574 | Single |  | 2020/11/06
US | JFL Enterprises, Inc. | Stink Factory | Cupcake | https://www.thestinkfactory.com/stickers/cupcake_sticker.html |  | $ 2.00 | Sheet | 2 | $ 1.00 | 10.16 x 17.173 | 174.19 | 0.00574 | Single |  | 2020/11/06
US | JFL Enterprises, Inc. | Stink Factory | Dirt | https://www.thestinkfactory.com/stickers/dirt_sticker.html |  | $ 2.00 | Sheet | 2 | $ 1.00 | 10.16 x 17.174 | 174.19 | 0.00574 | Single |  | 2020/11/06
US | JFL Enterprises, Inc. | Stink Factory | Dots Lime | https://www.thestinkfactory.com/stickers/dots-lime.html |  | $ 2.00 | Sheet | 2 | $ 1.00 | 10.16 x 17.175 | 174.19 | 0.00574 | Single |  | 2020/11/06
US | JFL Enterprises, Inc. | Stink Factory | Dots Strawberry | https://www.thestinkfactory.com/stickers/dots-strawberry.html |  | $ 2.00 | Sheet | 2 | $ 1.00 | 10.16 x 17.176 | 174.19 | 0.00574 | Single |  | 2020/11/06
US | JFL Enterprises, Inc. | Stink Factory | Dubble Bubble | https://www.thestinkfactory.com/stickers/dubble-bubble.html |  | $ 2.00 | Sheet | 2 | $ 1.00 | 10.16 x 17.177 | 174.19 | 0.00574 | Single |  | 2020/11/06
US | JFL Enterprises, Inc. | Stink Factory | Fireworks | https://www.thestinkfactory.com/stickers/fireworks_sticker.html |  | $ 2.00 | Sheet | 2 | $ 1.00 | 10.16 x 17.178 | 174.19 | 0.00574 | Single |  | 2020/11/06
US | JFL Enterprises, Inc. | Stink Factory | Fish | https://www.thestinkfactory.com/stickers/fish_sticker.html |  | $ 2.00 | Sheet | 2 | $ 1.00 | 10.16 x 17.179 | 174.19 | 0.00574 | Single |  | 2020/11/06
US | JFL Enterprises, Inc. | Stink Factory | Flower Power | https://www.thestinkfactory.com/stickers/flower_sticker.html |  | $ 2.00 | Sheet | 2 | $ 1.00 | 10.16 x 17.180 | 174.19 | 0.00574 | Single |  | 2020/11/06
US | JFL Enterprises, Inc. | Stink Factory | Fluffy Stuff Cotton Candy | https://www.thestinkfactory.com/stickers/fluffy-stuff.html |  | $ 2.00 | Sheet | 2 | $ 1.00 | 10.16 x 17.181 | 174.19 | 0.00574 | Single |  | 2020/11/06
US | JFL Enterprises, Inc. | Stink Factory | Fruit Punch | https://www.thestinkfactory.com/stickers/fruit_sticker.html |  | $ 2.00 | Sheet | 2 | $ 1.00 | 10.16 x 17.182 | 174.19 | 0.00574 | Single |  | 2020/11/06
US | JFL Enterprises, Inc. | Stink Factory | Garbage | https://www.thestinkfactory.com/stickers/garbage_sticker.html |  | $ 2.00 | Sheet | 2 | $ 1.00 | 10.16 x 17.183 | 174.19 | 0.00574 | Single |  | 2020/11/06
US | JFL Enterprises, Inc. | Stink Factory | Ghost Marshmallow | https://www.thestinkfactory.com/stickers/halloween-DrStinky-ghost.html |  | $ 2.00 | Sheet | 2 | $ 1.00 | 10.16 x 17.184 | 174.19 | 0.00574 | Single |  | 2020/11/06
US | JFL Enterprises, Inc. | Stink Factory | Gingerbread House | https://www.thestinkfactory.com/stickers/xmas-DrStinky-gingerbread.html |  | $ 2.00 | Sheet | 2 | $ 1.00 | 10.16 x 17.185 | 174.19 | 0.00574 | Single |  | 2020/11/06
US | JFL Enterprises, Inc. | Stink Factory | Grandma | https://www.thestinkfactory.com/stickers/grandma_sticker.html |  | $ 2.00 | Sheet | 2 | $ 1.00 | 10.16 x 17.186 | 174.19 | 0.00574 | Single |  | 2020/11/06
US | JFL Enterprises, Inc. | Stink Factory | Grandpa | https://www.thestinkfactory.com/stickers/grandpa_sticker.html |  | $ 2.00 | Sheet | 2 | $ 1.00 | 10.16 x 17.187 | 174.19 | 0.00574 | Single |  | 2020/11/06
US | JFL Enterprises, Inc. | Stink Factory | Grape | https://www.thestinkfactory.com/stickers/grape_sticker.html |  | $ 2.00 | Sheet | 2 | $ 1.00 | 10.16 x 17.188 | 174.19 | 0.00574 | Single |  | 2020/11/06
US | JFL Enterprises, Inc. | Stink Factory | Gummi Bear | https://www.thestinkfactory.com/stickers/gummi-bear_sticker.html |  | $ 2.00 | Sheet | 2 | $ 1.00 | 10.16 x 17.189 | 174.19 | 0.00574 | Single |  | 2020/11/06
US | JFL Enterprises, Inc. | Stink Factory | Hamburger | https://www.thestinkfactory.com/stickers/Hamburger_sticker.html |  | $ 2.00 | Sheet | 2 | $ 1.00 | 10.16 x 17.190 | 174.19 | 0.00574 | Single |  | 2020/11/06
US | JFL Enterprises, Inc. | Stink Factory | Hot Wings | https://www.thestinkfactory.com/stickers/hotwings_sticker.html |  | $ 2.00 | Sheet | 2 | $ 1.00 | 10.16 x 17.191 | 174.19 | 0.00574 | Single |  | 2020/11/06
US | JFL Enterprises, Inc. | Stink Factory | Jellybean | https://www.thestinkfactory.com/stickers/Jelly-Beans_sticker.html |  | $ 2.00 | Sheet | 2 | $ 1.00 | 10.16 x 17.192 | 174.19 | 0.00574 | Single |  | 2020/11/06
US | JFL Enterprises, Inc. | Stink Factory | Junior Mints | https://www.thestinkfactory.com/stickers/JRmints.html |  | $ 2.00 | Sheet | 2 | $ 1.00 | 10.16 x 17.193 | 174.19 | 0.00574 | Single |  | 2020/11/06
US | JFL Enterprises, Inc. | Stink Factory | Ketchup | https://www.thestinkfactory.com/stickers/ketchup_sticker.html |  | $ 2.00 | Sheet | 2 | $ 1.00 | 10.16 x 17.194 | 174.19 | 0.00574 | Single |  | 2020/11/06
US | JFL Enterprises, Inc. | Stink Factory | Lemonade | https://www.thestinkfactory.com/stickers/lemonade_sticker.html |  | $ 2.00 | Sheet | 2 | $ 1.00 | 10.16 x 17.195 | 174.19 | 0.00574 | Single |  | 2020/11/06
US | JFL Enterprises, Inc. | Stink Factory | Marshmallow | https://www.thestinkfactory.com/stickers/Marshmallow_sticker.html |  | $ 2.00 | Sheet | 2 | $ 1.00 | 10.16 x 17.196 | 174.19 | 0.00574 | Single |  | 2020/11/06
US | JFL Enterprises, Inc. | Stink Factory | Mint Chocolate Chip | https://www.thestinkfactory.com/stickers/Mint-Chocolate-Chip_sticker.html |  | $ 2.00 | Sheet | 2 | $ 1.00 | 10.16 x 17.197 | 174.19 | 0.00574 | Single |  | 2020/11/06
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

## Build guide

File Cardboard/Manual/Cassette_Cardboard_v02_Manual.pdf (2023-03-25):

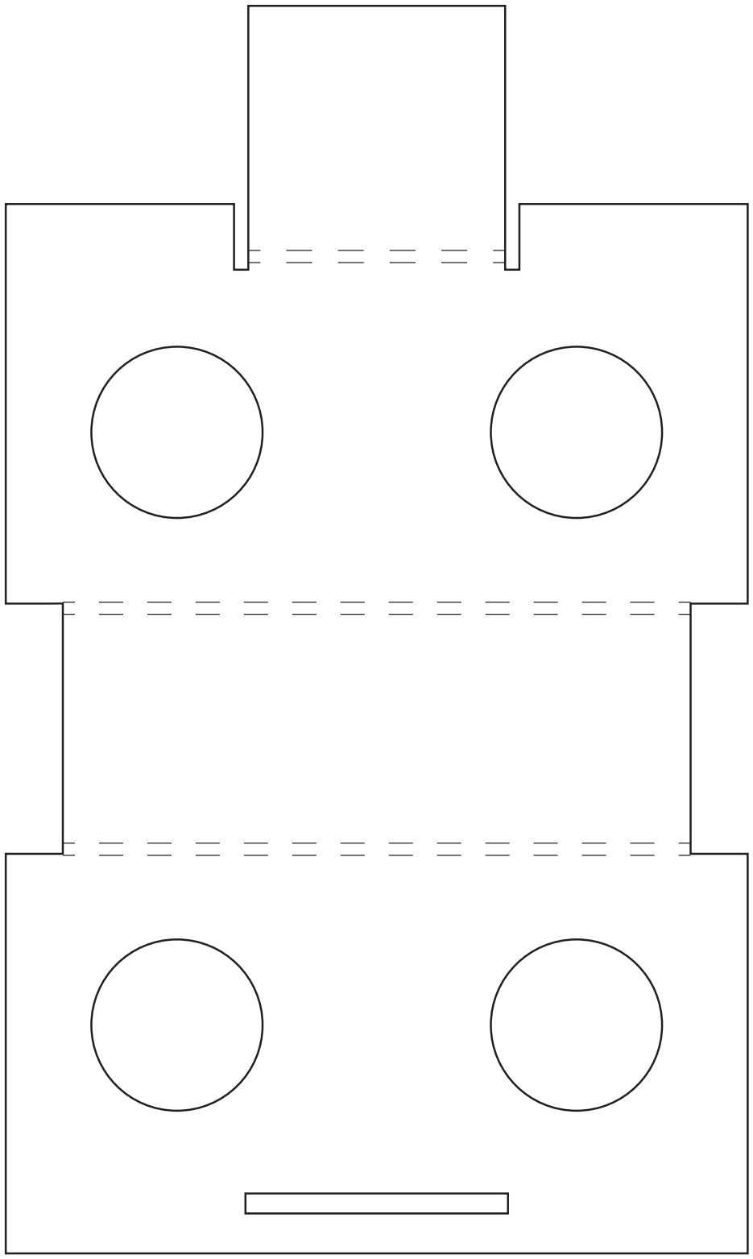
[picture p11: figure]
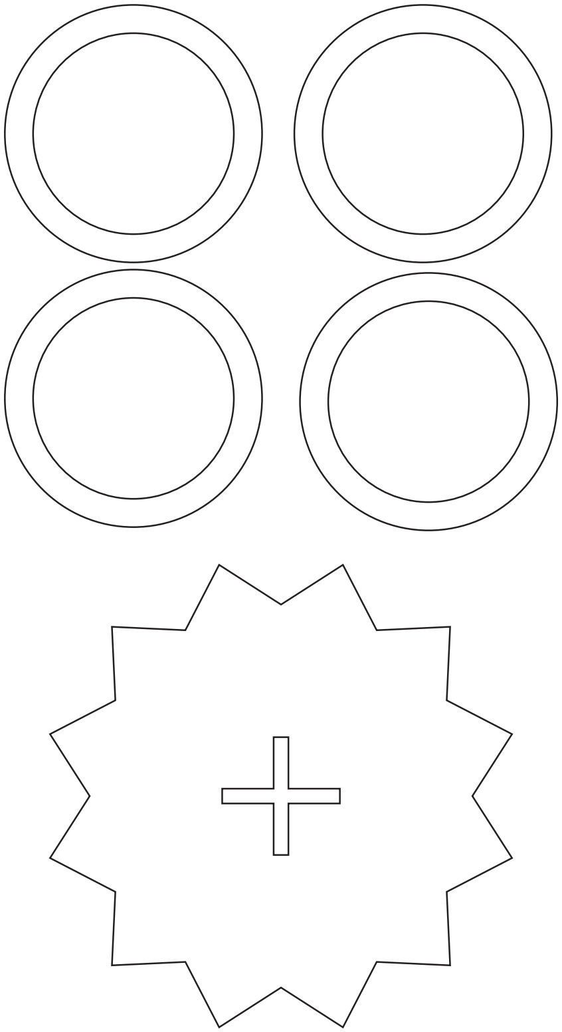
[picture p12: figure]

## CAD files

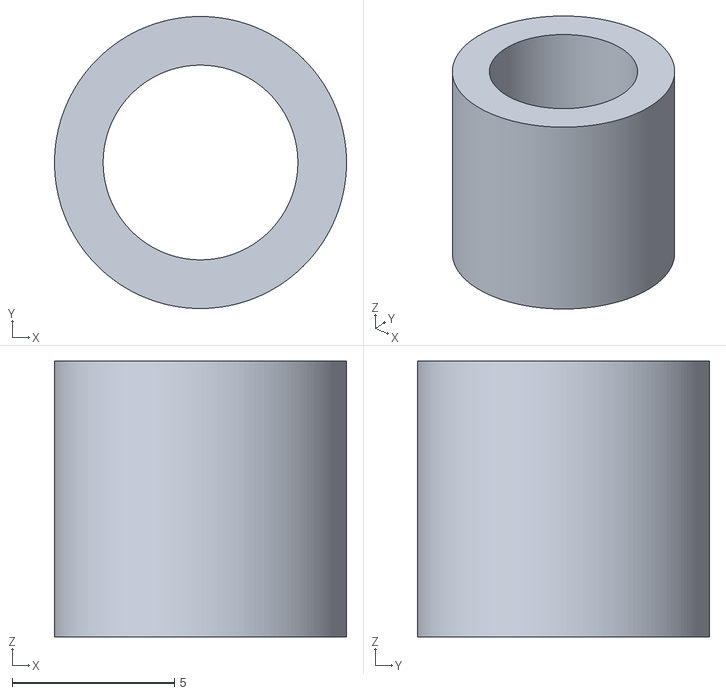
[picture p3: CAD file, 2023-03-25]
3D_Print/STL/SaP_Nylon_Roller.stl
9.00 x 9.00 x 8.50

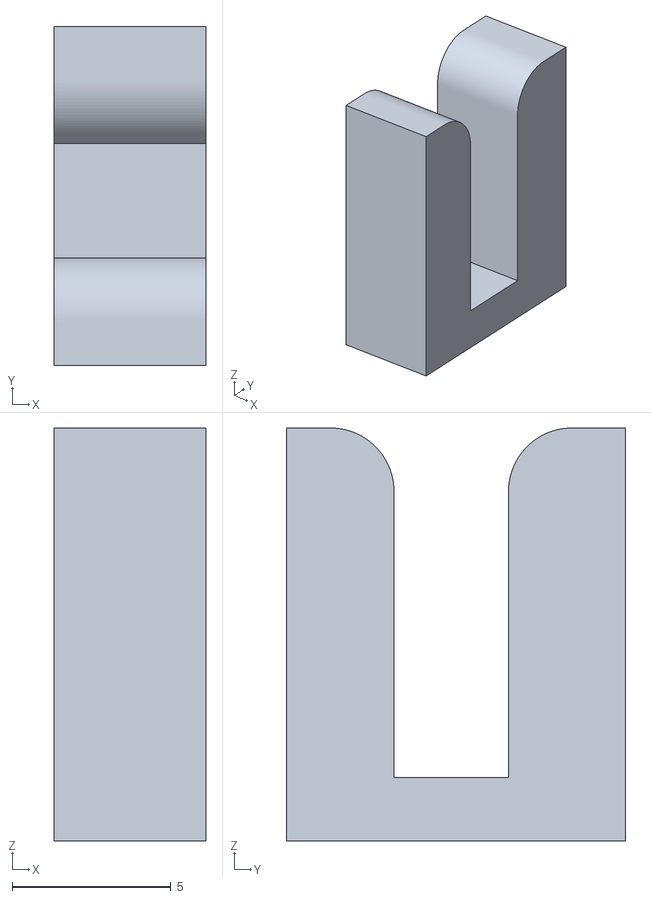
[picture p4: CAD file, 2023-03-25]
3D_Print/STL/SaP_Nylon_Comb.stl
4.78 x 10.7 x 13.0

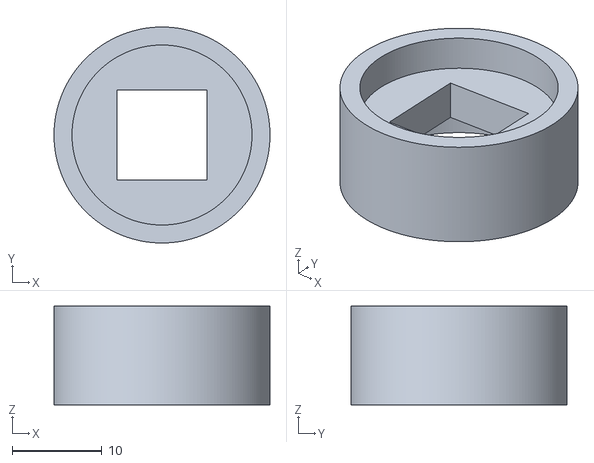
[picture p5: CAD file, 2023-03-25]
3D_Print/STL/SaP_Nylon_Spool.stl
24.0 x 24.0 x 11.0

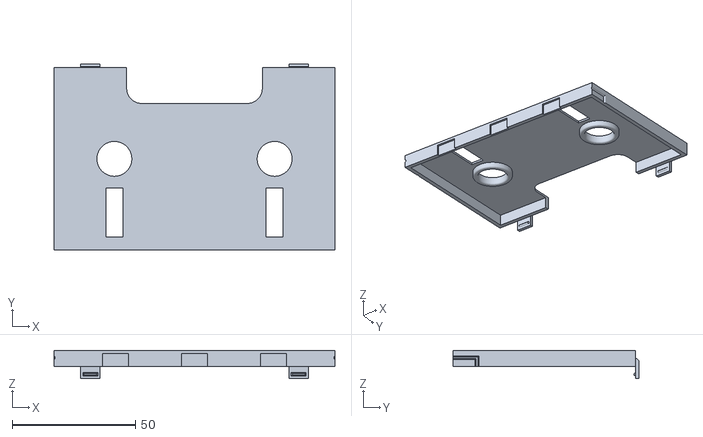
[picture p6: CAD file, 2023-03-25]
3D_Print/STL/SaP_Nylon_CaseTop.stl
114.0 x 75.5 x 11.5

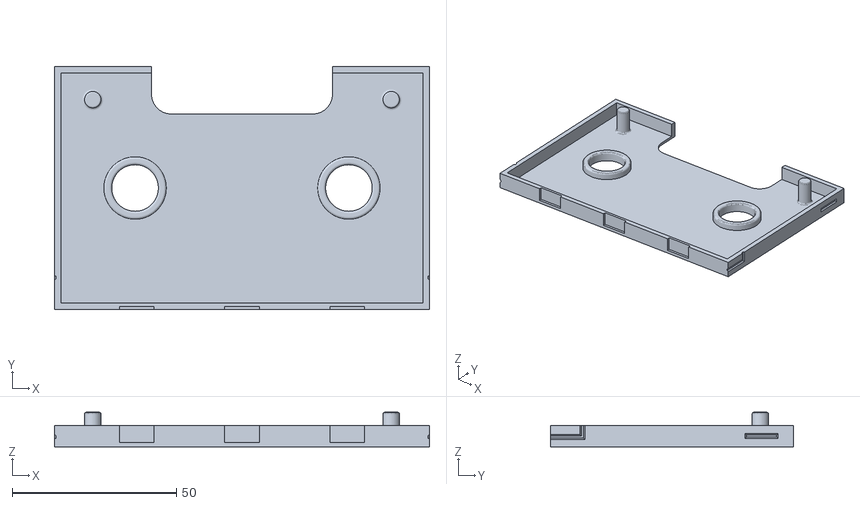
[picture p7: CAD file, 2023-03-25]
3D_Print/STL/SaP_Nylon_CaseBottom.stl
114.0 x 74.0 x 10.5

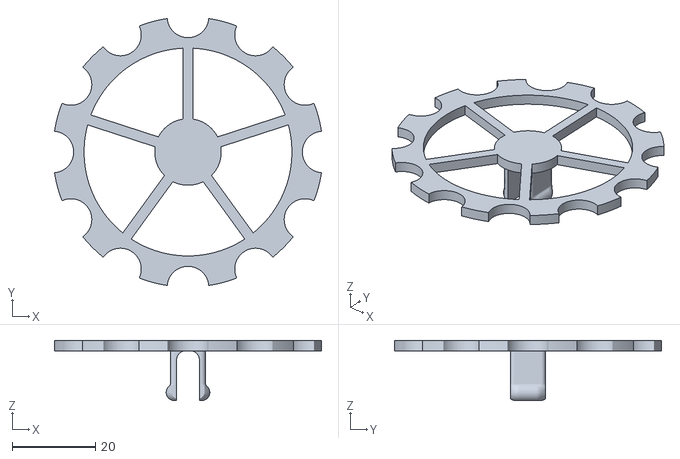
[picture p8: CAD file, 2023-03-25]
3D_Print/STL/SaP_Nylon_Driver.stl
64.2 x 64.2 x 14.5

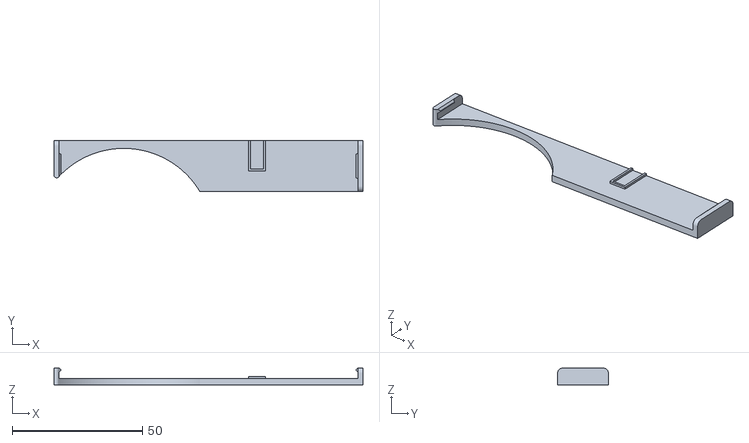
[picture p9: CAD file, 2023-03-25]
3D_Print/STL/SaP_Nylon_ScratchPlate.stl
118.5 x 19.5 x 6.50

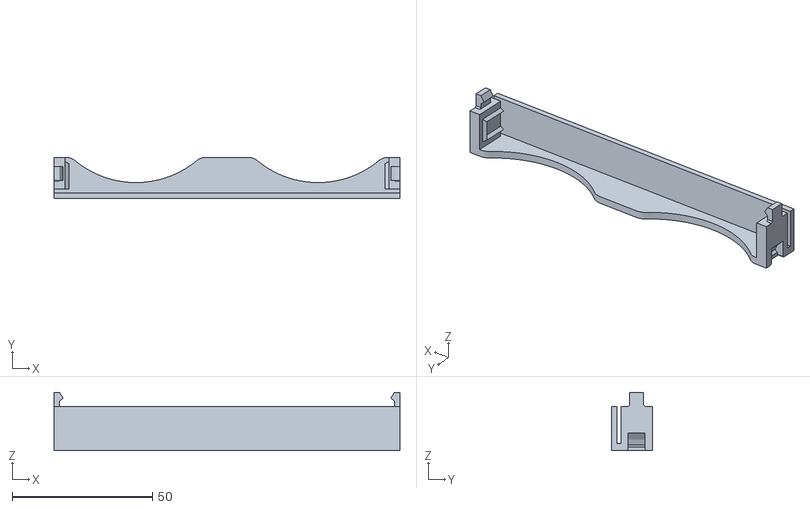
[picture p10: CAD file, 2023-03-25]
3D_Print/STL/SaP_Nylon_Stack.stl
123.5 x 14.8 x 20.8

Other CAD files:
3D_Print/Cassette_3dPrinted_v69.f3d
